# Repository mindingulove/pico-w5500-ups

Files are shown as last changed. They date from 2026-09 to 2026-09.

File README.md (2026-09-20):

# Pico W5500 UPS Battery Monitor

Firmware for a Raspberry Pi Pico UPS controller using W5500 Ethernet and I2C peripherals.

### Assembled DeskPi rack build

<table>
  <tr>
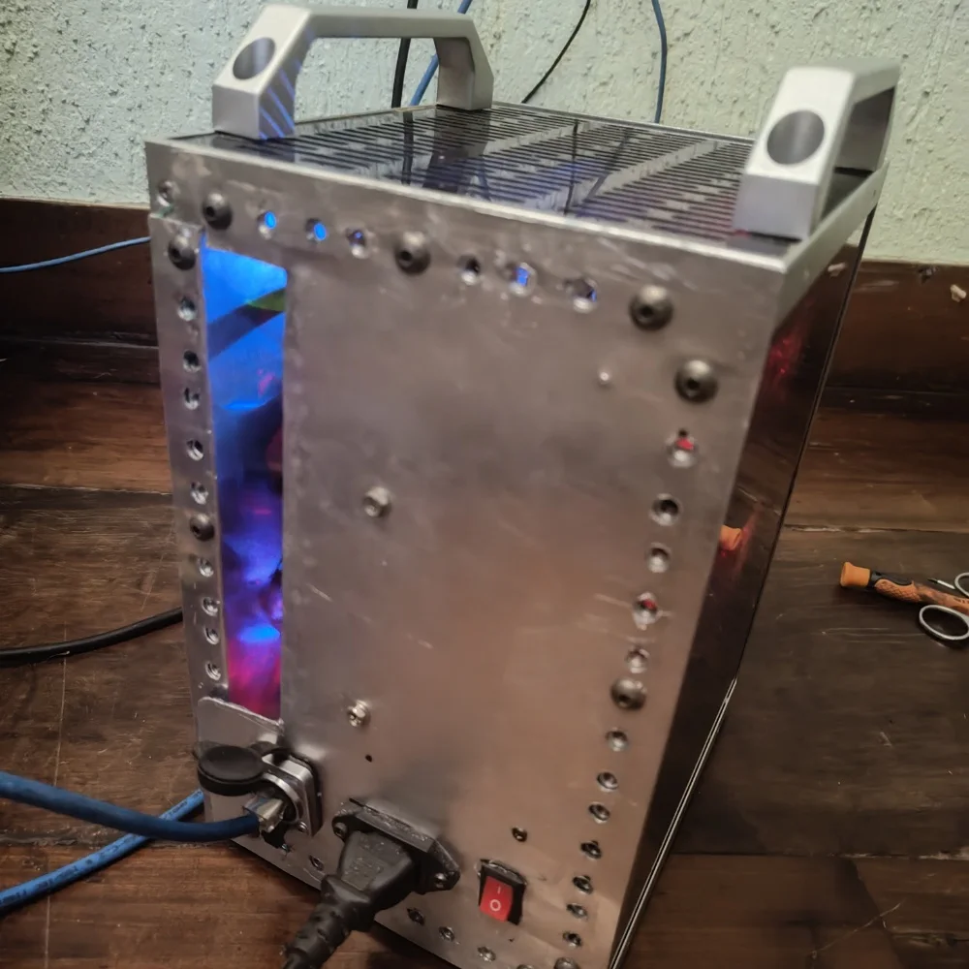
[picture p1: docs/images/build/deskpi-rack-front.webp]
Front of the assembled UPS and DeskPi rack
    <td></td>
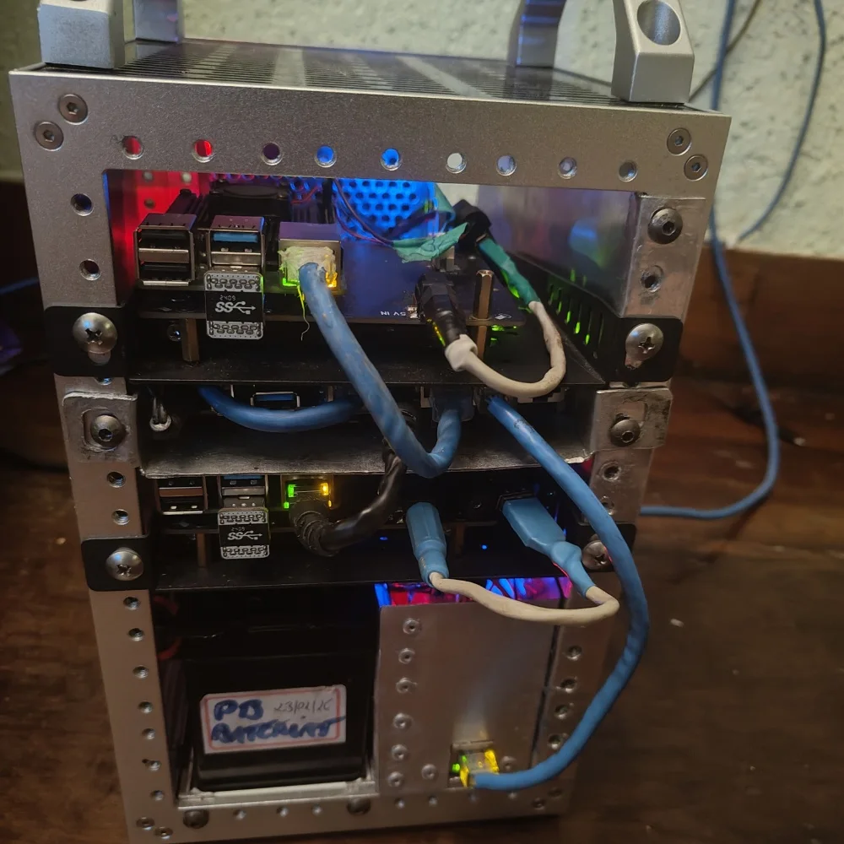
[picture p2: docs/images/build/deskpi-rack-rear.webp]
Rear of the assembled UPS and DeskPi rack
    <td></td>
  </tr>
  <tr>
    <td align="center">Enclosed UPS and rack</td>
    <td align="center">DeskPi rack installation and cabling</td>
  </tr>
</table>

## Hardware

| Device | Interface / address | Purpose |
| --- | --- | --- |
| W5500-EVB-Pico | RP2040 + SPI W5500 Ethernet | Main controller, firmware execution and wired network interface |
| ISO154x | Isolated I2C pass-through | Galvanic isolation between the Pico I2C bus and isolated-side peripherals |
| PC817 two-channel board | Pi GPIO17 to ADS1115 A0/A1 | Isolated host-alive and final-shutdown sensing; both ground-link jumpers must be removed |
| XL9535 | `0x20`-`0x27` | Relay outputs |
| ADS1115 | `0x48`-`0x4B` | Isolated PC817 output sensing; required for outage-time relay cutoff |
| AT24C256 | `0x50`-`0x57` | Persistent battery estimate and configuration |
| LTC2944 | `0x64`-`0x67` | Battery voltage, current and temperature |
| Mini 5 V DC-DC buck | Power | Local regulated 5 V rail |
| Isolated 12 V DC-DC converter | Isolated power | Regulated, galvanically isolated 12 V supply |
| SC-120W-12 UPS/charger | Mains, battery and 12 V output | Main 120 W supply and battery charger |
| Wide-input 5 V USB converter | Power | Regulated 5 V supply for USB-powered loads |

### Bill of materials

AliExpress listings and available variants can change. Match the selected
voltage, current rating, connector pitch and module pinout to the photographed
hardware before ordering or energizing anything.

| Photo | Part and purchase link | Use and required changes |
| --- | --- | --- |
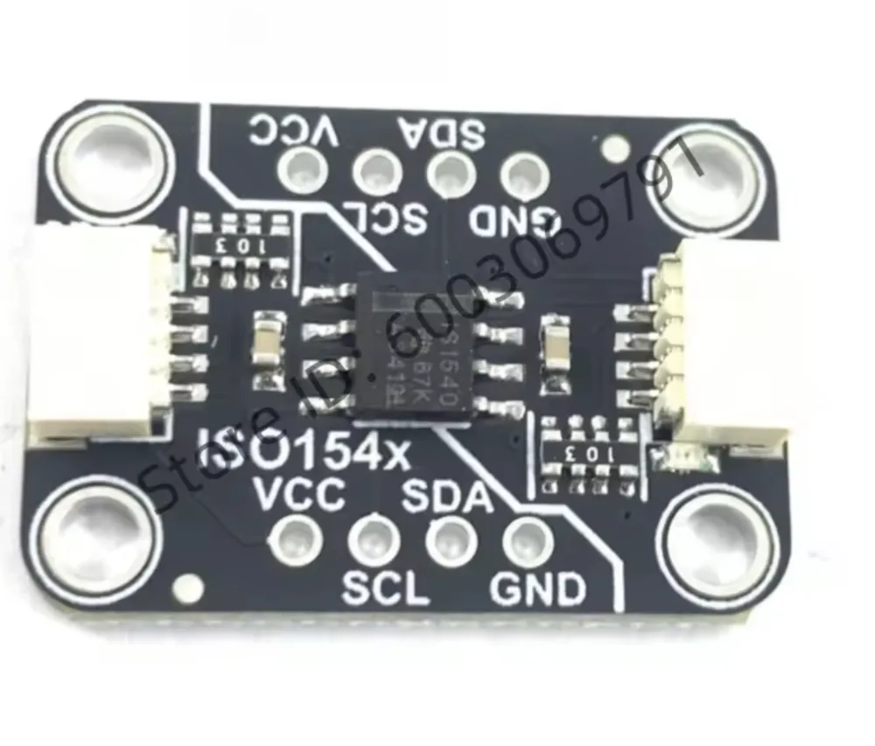
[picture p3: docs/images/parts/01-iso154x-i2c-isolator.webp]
ISO154x I2C isolator module
|  | [ISO154x bidirectional I2C isolator module](https://pt.aliexpress.com/item/1005011832652644.html) | Galvanically isolates the I2C domains. Supply each side from its own domain and do not join grounds across the barrier. |
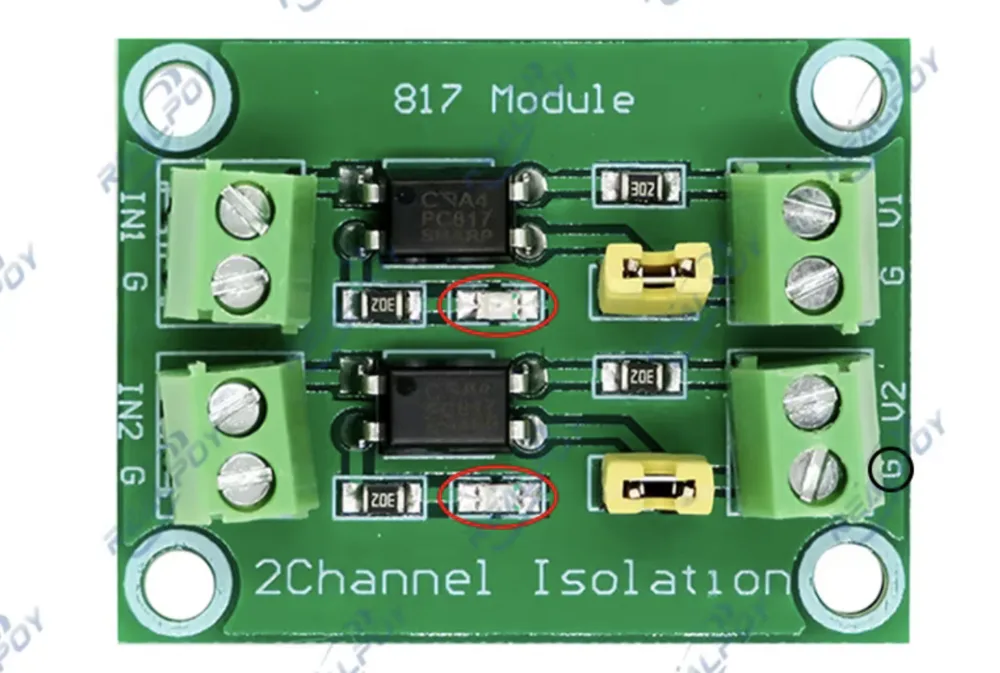
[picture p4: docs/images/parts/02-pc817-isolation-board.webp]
Two-channel PC817 isolation board
|  | [Two-channel PC817 optocoupler isolation board](https://pt.aliexpress.com/item/1005009042140520.html) | Isolates the two Raspberry Pi GPIO17 host-alive signals before ADS1115 measurement. **Remove both yellow jumpers before use**; installed jumpers connect the input and output grounds and defeat galvanic isolation. |
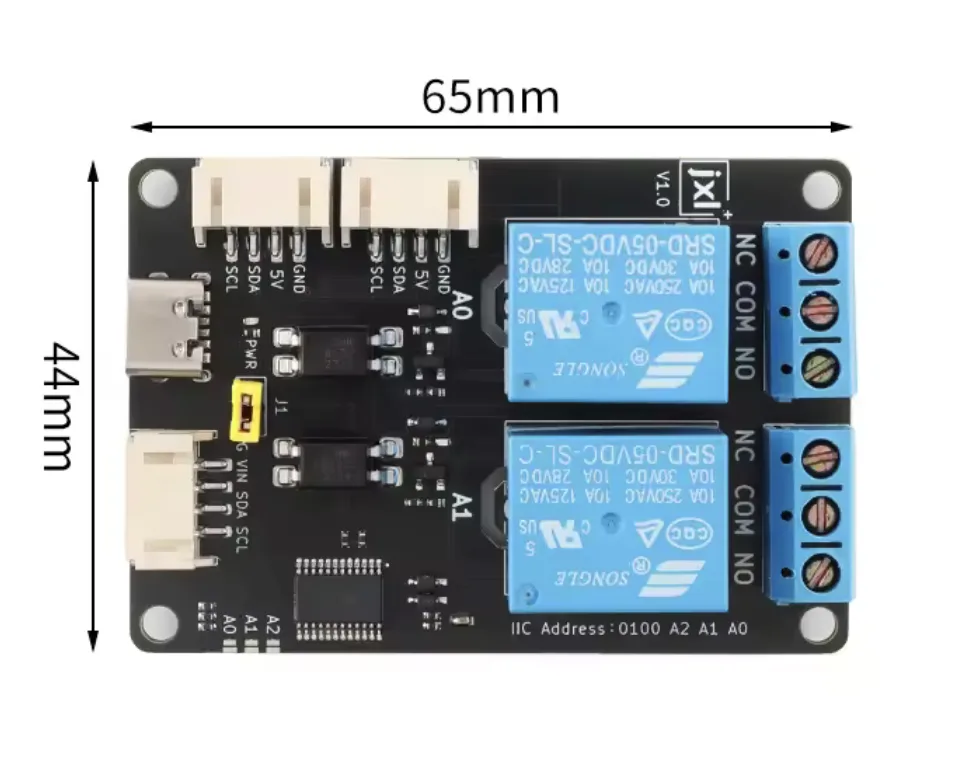
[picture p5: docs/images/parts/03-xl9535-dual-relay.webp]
XL9535 two-channel relay board
|  | [XL9535 I2C relay module](https://pt.aliexpress.com/item/1005005775051224.html) | Two output relays, detected by firmware at address `0x20` by default. This build uses the 5 V relay-board variant. |
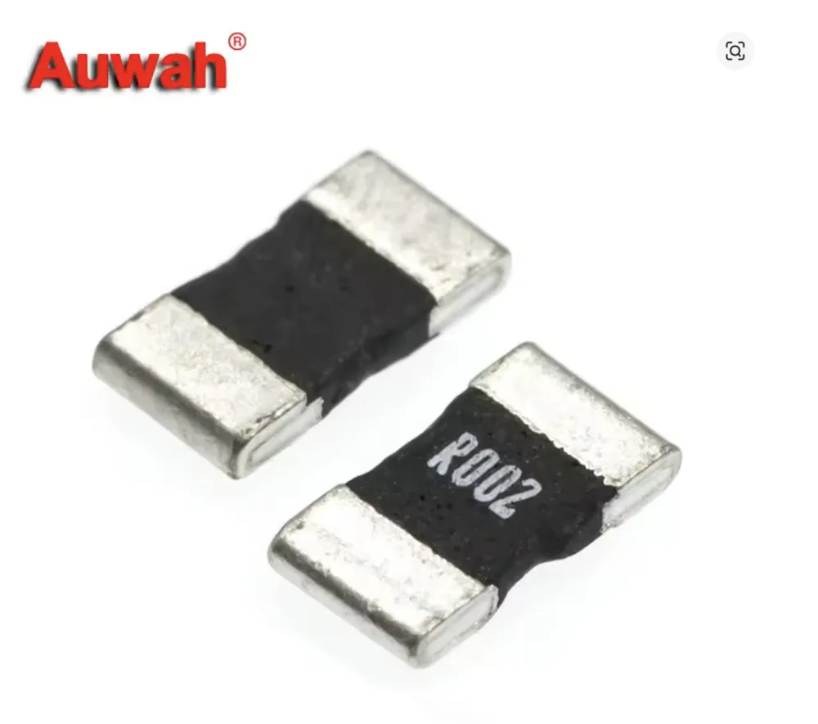
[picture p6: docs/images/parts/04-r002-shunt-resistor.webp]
R002 two milliohm shunt resistor
|  | [R002 shunt resistor](https://pt.aliexpress.com/item/1005003339688820.html) | `0.002 ohm` current shunt used to modify the LTC2944 board below. The firmware constant `LTC_SHUNT_OHMS` is set to `0.002f`. |
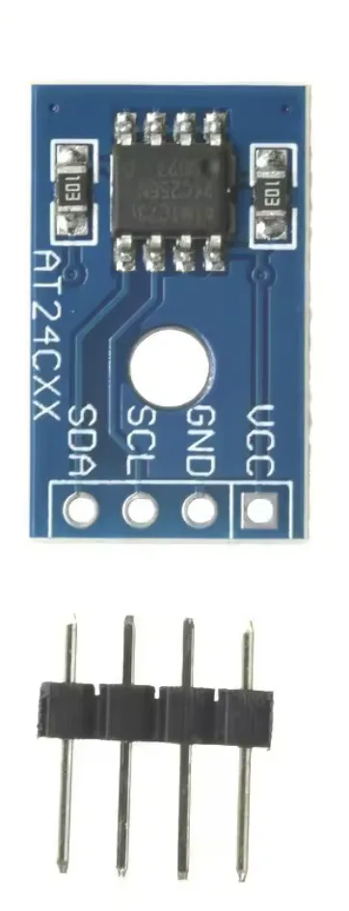
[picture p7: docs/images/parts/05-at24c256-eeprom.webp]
AT24C256 EEPROM module
|  | [AT24C256 I2C EEPROM module](https://pt.aliexpress.com/item/1005007083692220.html) | Stores persistent battery state, configuration and low-battery lockout; address `0x50` by default. |
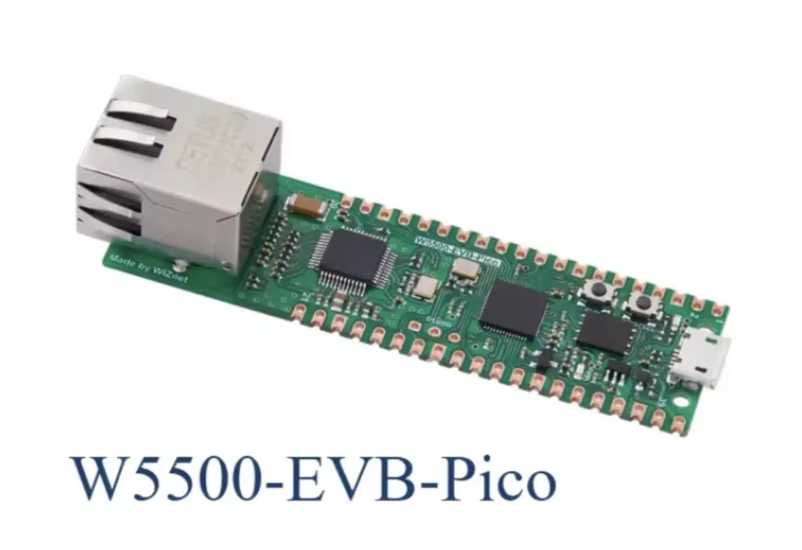
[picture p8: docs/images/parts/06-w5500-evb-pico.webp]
WIZnet W5500-EVB-Pico board
|  | [WIZnet W5500-EVB-Pico](https://pt.aliexpress.com/item/1005008613789535.html) | RP2040 controller with wired W5500 Ethernet. The custom PCB below plugs onto it through female headers. |
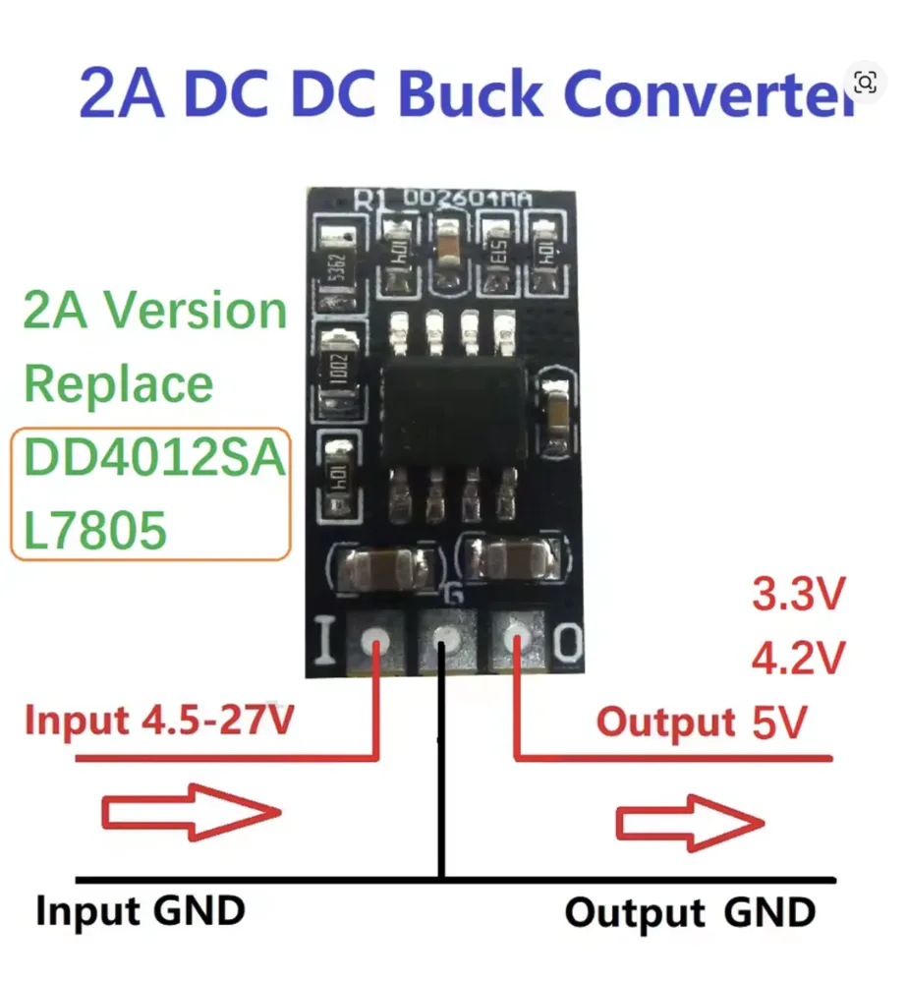
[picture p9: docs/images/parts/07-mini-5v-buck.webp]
Miniature DC-DC buck converter
|  | [Mini DC-DC buck converter](https://pt.aliexpress.com/item/1005004522623517.html) | Use the 5 V output variant shown for the local 5 V rail; verify the output with a meter before connecting electronics. |
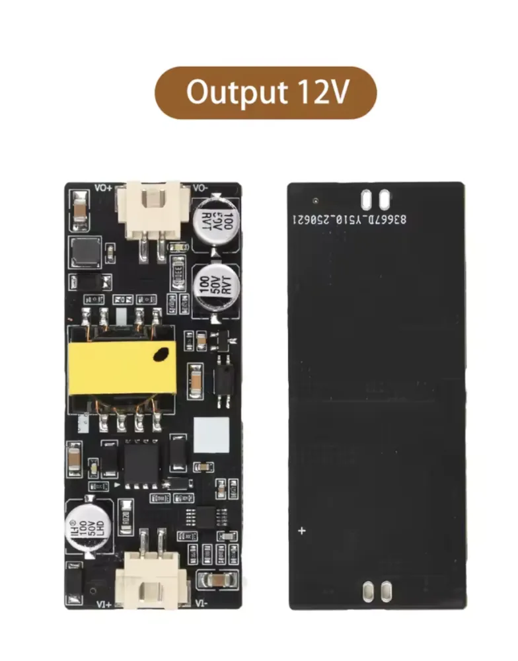
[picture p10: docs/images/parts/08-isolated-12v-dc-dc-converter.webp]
Isolated DC-DC converter with 12 volt output
|  | [Isolated 12 V DC-DC converter module](https://pt.aliexpress.com/item/1005009914339871.html) | Provides a galvanically isolated, regulated 12 V supply. Use the 12 V output variant shown and confirm input range, polarity, isolation and output voltage for the purchased option. |
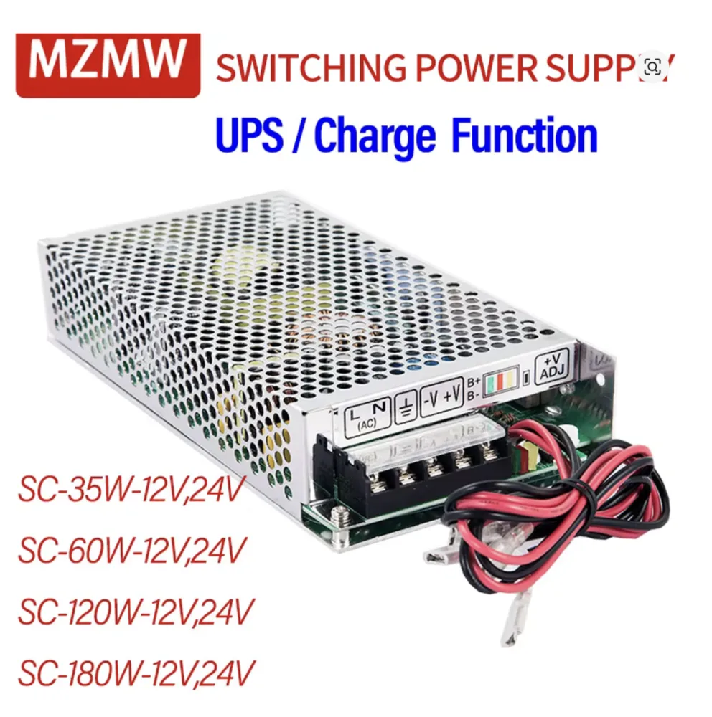
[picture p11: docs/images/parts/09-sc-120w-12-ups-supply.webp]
SC-120W-12 UPS and battery charger power supply
|  | [MZMW SC-series UPS/charger supply](https://pt.aliexpress.com/item/1005005835163230.html) | The pictured build uses the **SC-120W-12 (120 W, 12 V)** option as the mains supply and battery charger. |
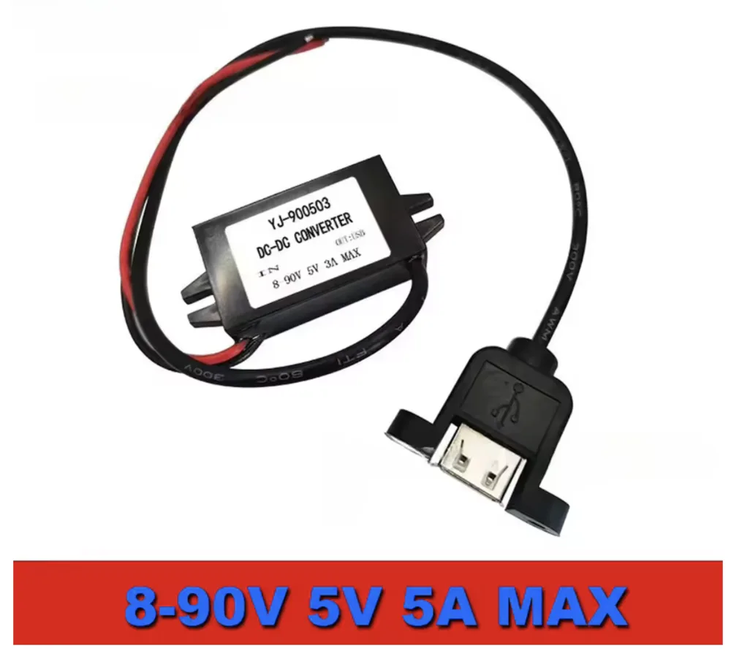
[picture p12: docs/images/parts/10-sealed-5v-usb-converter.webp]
Sealed wide-input 5 volt USB converter
|  | [Wide-input 5 V USB DC-DC converter](https://pt.aliexpress.com/item/1005006466617097.html) | Provides a regulated USB 5 V output. Seller photos show conflicting maximum-current claims, so size and fuse it from the rating printed on the received unit. |
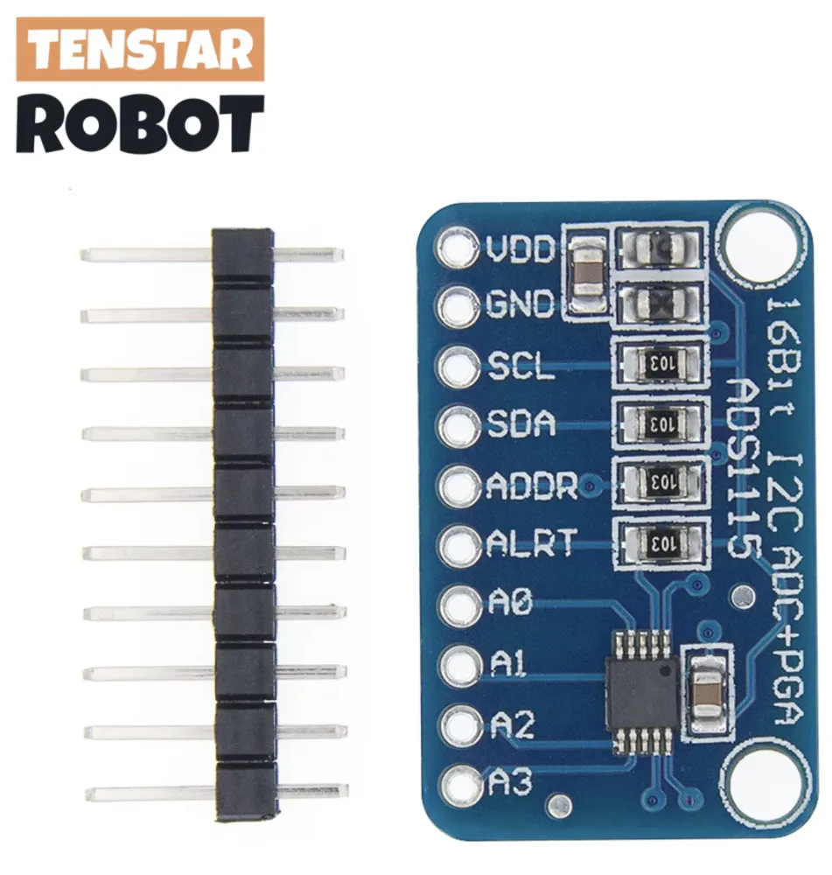
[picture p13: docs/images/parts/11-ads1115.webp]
ADS1115 I2C analog to digital converter
|  | [ADS1115 16-bit I2C ADC module](https://pt.aliexpress.com/item/1005005973975124.html) | Reads the isolated PC817 outputs on A0/Pi1 and A1/Pi2. Tie ADDR to the ADS-side GND for address `0x48`. |
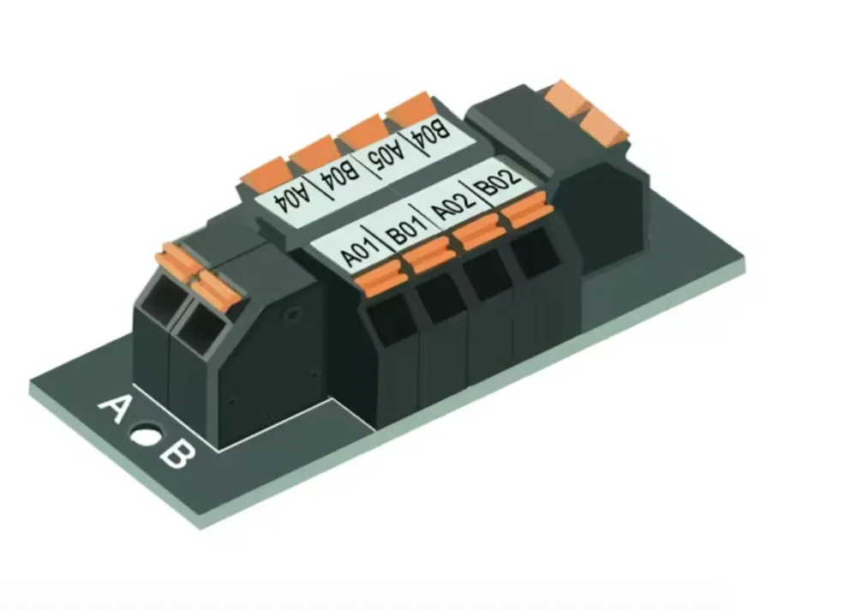
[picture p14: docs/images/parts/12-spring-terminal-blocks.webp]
Spring terminal block connectors
|  | [Spring terminal block connectors](https://pt.aliexpress.com/item/1005010494299157.html) | Board wiring connectors. Select the pitch and pole count that match the PCB footprints and verify orientation before soldering. |
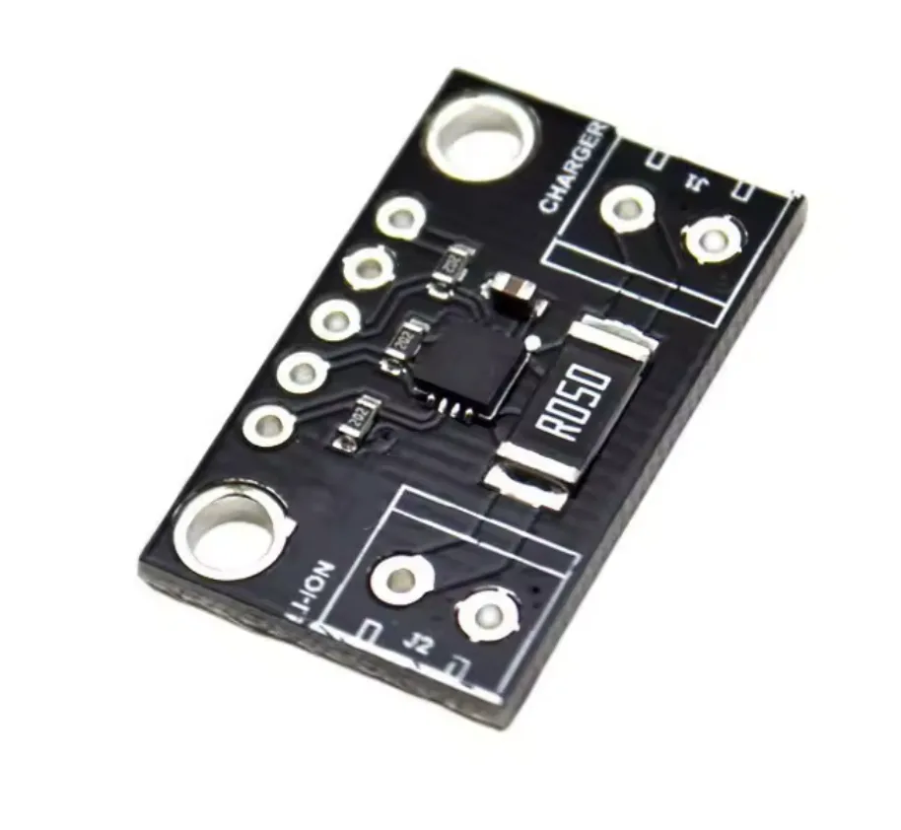
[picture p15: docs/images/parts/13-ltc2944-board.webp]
LTC2944 battery gauge board with original R050 shunt
|  | [LTC2944 battery monitor board](https://pt.aliexpress.com/item/1005006332511347.html) | Measures battery voltage, current and temperature. **Replace the board's original `R050` shunt with the `R002` part listed above** so the hardware matches the firmware's `0.002 ohm` calibration. |
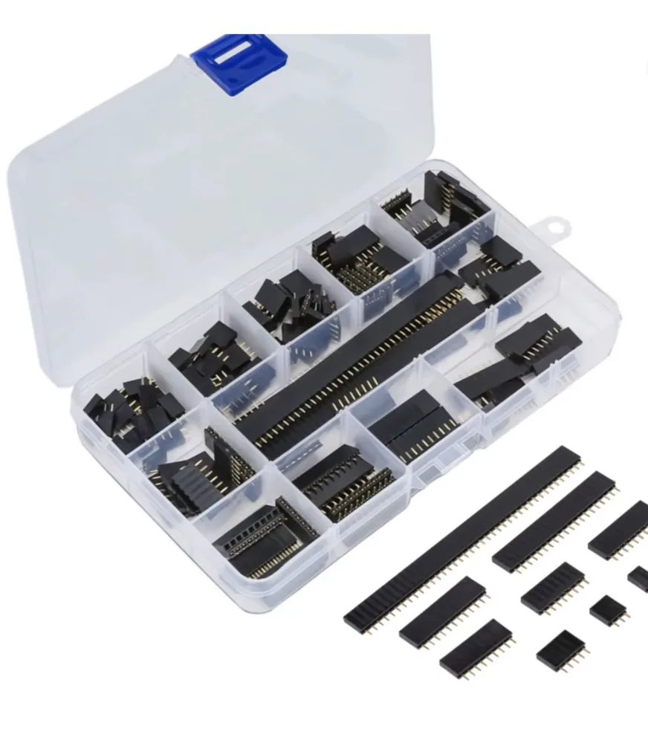
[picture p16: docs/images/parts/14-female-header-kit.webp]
Female PCB header assortment
|  | [Female PCB header assortment](https://pt.aliexpress.com/item/4000523047541.html) | Connects the custom piggyback PCB to the W5500-EVB-Pico. Cut/select the correct lengths and confirm pin alignment before insertion. |

Product photos are identification references supplied by the project owner.
Product names, trademarks and image rights remain with their respective owners.

> [!WARNING]
> The SC-120W supply exposes hazardous mains voltage, and a 12 V battery can
> deliver destructive fault current. Use a grounded enclosure, strain relief,
> insulated covers and correctly rated fuses close to the battery and source.
> Do not work on the assembly while mains or battery power is connected.

### W5500-EVB-Pico piggyback PCB

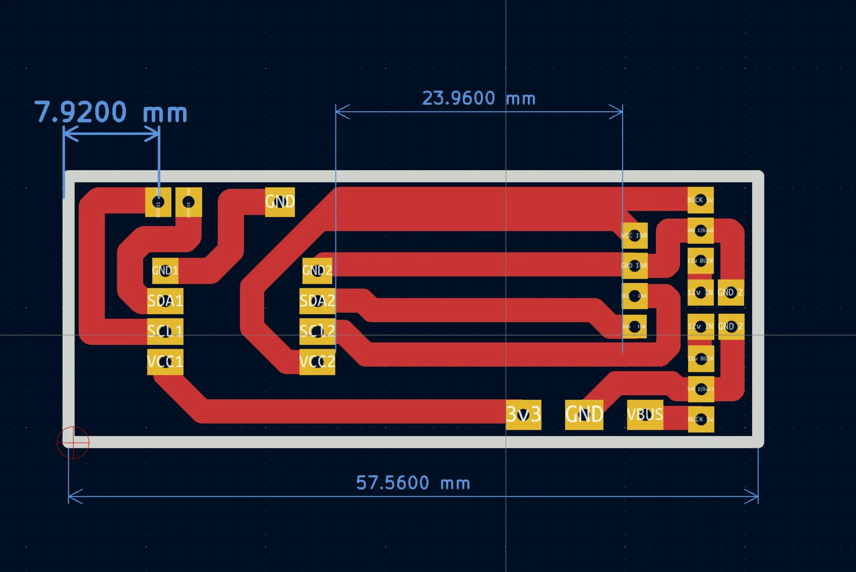
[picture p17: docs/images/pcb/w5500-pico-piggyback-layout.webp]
W5500-EVB-Pico piggyback PCB layout


The custom board is approximately `57.56 mm` long and mounts to the
W5500-EVB-Pico using the [female header
strips](https://pt.aliexpress.com/item/4000523047541.html) listed above. The
editable KiCad board/project and supplied manufacturing outputs are included
under [`hardware/w5500-piggyback`](hardware/w5500-piggyback). The original
folder did not contain a schematic for this board.

- [`source/w5500.kicad_pcb`](hardware/w5500-piggyback/source/w5500.kicad_pcb)
  is the editable board layout.
- [`source/w5500.kicad_pro`](hardware/w5500-piggyback/source/w5500.kicad_pro)
  is the KiCad project configuration.
- [`fabrication/gerber`](hardware/w5500-piggyback/fabrication/gerber) contains
  the supplied Gerber, drill and Gerber-job files.
- [`fabrication/cnc`](hardware/w5500-piggyback/fabrication/cnc) contains the
  supplied isolation-routing, outline and drill CNC files.

The fabrication files are snapshots from the original design folder. Open the
PCB in KiCad, run DRC, verify the board outline, connector orientation and
clearances, and regenerate the manufacturing output before ordering a board or
running a CNC job.

The Pico uses GP12 for SDA and GP13 for SCL. Devices within each ISO1540 power
domain share that domain's ground; do not bridge the isolation barrier. SDA and
SCL must remain at 3.3 V logic levels.

When ADS1115 is missing, firmware uses successful XL9535 relay commands only as an estimated output state. API and MQTT status mark this with `sensed_estimated: true` and `sense_source: "relay_command"`. This is not a physical measurement and never authorizes relay cutoff during an outage.

Power the ADS1115 from its local isolated-side 3.3 V supply. Its GND and ADDR
pins connect to the PC817 output-side GND, selecting I2C address `0x48`. Connect
A0 to the Pi1 PC817 output and A1 to the Pi2 PC817 output; never connect either
Pi power rail or Pi-side ground directly across the isolation barrier.

On the two-channel PC817 board, remove both yellow ground-link jumpers before
connecting it. Leaving either jumper installed bridges that channel's input and
output grounds and defeats the isolation relied upon by this wiring. With the
board fully disconnected and unpowered, verify that input-side GND and
output-side GND are no longer continuous before installing it.

The installed PC817 outputs are active-low and calibrated for the measured
GPIO17 interface levels: approximately `0.017 V` while running and `0.58 V`
after the shutdown signal is released. Firmware must first observe an ADS
channel at or below `0.10 V` for 10 seconds while the Pi is running. After the
shutdown request, it must observe the channel at or above `0.45 V` for 30
seconds before permitting that Pi's relay to turn off. Readings between the two
thresholds are indeterminate and fail closed. A channel that starts in the OFF
range cannot authorize cutoff because the preceding running state was not seen.
The API/MQTT `ads_v` field displays the inverted logical Pi voltage
(`3.30 V - PC817 output`); `ads_raw_v` retains the actual ADC measurement used
by the safety interlock.

For GPIO-based host-alive sensing, install `ups_gpio_alive.service` so GPIO17
(physical pin 11) is driven HIGH after boot. Install the executable
`ups_gpio_shutdown_final` as
`/usr/lib/systemd/system-shutdown/ups_gpio_shutdown_final`; it drives GPIO17
LOW only for the final `poweroff` or `halt` phase, after normal services have
stopped. The hook runs `sync` and fails closed unless every persistent
filesystem visible in `/proc/mounts` is unmounted or read-only. Do not use an
ordinary service `ExecStop` for the LOW transition because that runs too early
to prove shutdown is complete.

## Network

- Static IP: `192.168.6.122`
- HTTP status: `http://192.168.6.122/api/status`
- NUT server: `192.168.6.122:3493`, UPS name `pico-ups`
- MQTT broker: `192.168.6.245:1883`
- MQTT base topic: `ups/battery/main`

MQTT connection requires a working Ethernet link. `rc=-2` means the TCP connection to the broker failed.

## PVE-UPS / NUT

The Pico exposes a read-only NUT protocol endpoint for PVE-UPS on TCP port
`3493`. Configure the PVE-UPS source as:

- Type: `NUT server`
- Host: `192.168.6.122`
- Port: `3493`
- UPS name: `pico-ups`
- Username/password: leave blank

The endpoint implements the anonymous `LIST VAR` operation used by PVE-UPS and
also supports `LIST UPS`, `VER`, `PROTVER`, and `LOGOUT`. It does not accept NUT
write or instant commands. Keep TCP port 3493 restricted to the trusted
management LAN because the NUT protocol is unencrypted.

`ups.status` changes to `OB` only after battery discharge is confirmed for five
seconds. Once on battery, it remains latched until voltage is at least `13.60 V`
with non-discharging current for 30 seconds. This prevents falling server load
during shutdown from being misreported as restored utility power. Sensor loss
is reported as `NOCOMM`, never as `OL`.

With PVE-UPS configured to shut PBS down first and the Proxmox host last at
`10%` charge, the Pico arms a RAM-only external-shutdown handoff when its NUT
state is `OB` and SOC reaches `10%`. Arming never authorizes relay cutoff by
itself. The Pico waits at least 60 seconds and requires every still-powered
host's ADS/PC817 channel to complete the normal running-to-final-OFF proof.
Only then does it persist the low-battery lockout and remove relay power.

If utility returns while PVE-UPS is completing shutdown, the handoff remains
armed for five minutes. A completed final-OFF proof during that window causes
the safe relay cutoff, followed by the normal confirmed automatic restoration,
so halted hosts receive an OFF-to-ON start. If no complete proof arrives, the
RAM latch expires without changing a relay. If PVE-UPS fails, the existing 5%
local shutdown agents remain the fallback. If both methods fail, GPIO stays in
the running state and relay cutoff remains blocked, including at `10.8 V`.
The status API exposes `pve_ups_handoff_armed`,
`pve_ups_handoff_cutoff_ready`, and
`pve_ups_handoff_recovery_remaining_sec` for diagnosis.

The Pico publishes `battery.runtime` only while it has a meaningful live
discharge estimate. PVE-UPS can always use its on-battery and charge triggers;
the runtime trigger becomes available during a measurable discharge. Output
load percentage is deliberately omitted because the measured signed battery
power is not the same as UPS output load relative to a rated capacity.

## Home Assistant: MQTT And HTTP Sensors

Both telemetry paths are intentionally available at the same time:

- MQTT discovery creates source-specific entities such as
  `sensor.ups_battery_main_mqtt_soc`,
  `sensor.ups_battery_main_mqtt_power`, and
  `sensor.ups_battery_main_mqtt_runtime`. These entities are attached to the
  `Server UPS` MQTT device. Their concise entity names (`SOC`, `Voltage`,
  `Current`, `Power`, `Temperature`, `Energy`, and `Runtime`) keep dashboard
  headings and graph legends readable without changing their entity IDs.
- The Home Assistant package polls `GET /api/status` every 15 seconds through
  `sensor.ups_pico_raw_status` and keeps the existing HTTP-derived entities,
  including `sensor.ups_battery_main_soc`,
  `sensor.ups_battery_main_power`, and
  `sensor.ups_battery_main_runtime`. Their display names include `HTTP` so the
  two sources are unambiguous while existing dashboard entity IDs continue to
  work.

MQTT and HTTP values should normally match, allowing either path to be graphed
or used in automations. The MQTT runtime text reports `Charging`, `Idle`, or a
remaining-time value instead of exposing the firmware's internal `-1` sentinel.
The numeric MQTT runtime-minutes entity has no numeric state while charging or
idle. The Pico subscribes to Home Assistant's `homeassistant/status` birth
topic and republishes discovery when Home Assistant reconnects.

`power_w` is signed battery power flow, not a direct measurement of total server
load. Positive values indicate charging and negative values indicate discharge.
`sensor.ups_battery_main_estimated_load_w` remains a Home Assistant-configured
outage-load estimate used when a live discharge runtime cannot be calculated.

## Local Configuration

Create the private firmware configuration before building:

```sh
cp ups_secrets.example.h ups_secrets.h
```

Set `UPS_OTA_TOKEN` and `UPS_CALIBRATION_TOKEN` to different long random
values. Set `UPS_MQTT_USER` and `UPS_MQTT_PASSWORD` when the broker requires
authentication; leave both empty for anonymous MQTT. Keep the matching
calibration token in the Home Assistant `rest_command` URLs. For the included
Home Assistant package, copy `homeassistant_ups_package.example.yaml` to
`homeassistant_ups_package.yaml` and replace
`replace_with_calibration_token` locally. The real `ups_secrets.h`, Home
Assistant package, `.env`, generated firmware, and private `plans/` tree are
excluded from Git.

## Build

Use the provided script so every firmware has the required OTA flash layout:

```sh
./build_ota.sh
```

The layout is `2 MB flash: 1 MB sketch + 1 MB LittleFS`. Output files are:

```text
build/ota/ups_battery_monitor.ino.bin
build/ota/ups_battery_monitor.ino.uf2
```

Do not build OTA releases with `2 MB (no FS)`. OTA staging and rollback will not work without the 1 MB LittleFS partition.

## First Installation

The OTA-capable firmware must be installed once over USB:

1. Hold BOOTSEL while connecting the Pico.
2. Copy `build/ota/ups_battery_monitor.ino.uf2` to the `RPI-RP2` volume.
3. Confirm the serial log or `/api/status` reports `Firmware: pve-ups-handoff-2026-09-20`.
4. Confirm Ethernet link and `192.168.6.122` are reachable.

Future updates can use Ethernet.

### Upgrading From A No-LittleFS Build

Check the `hardware.littlefs` field returned by `/api/status`. If it is `false`, the installed firmware uses the old `2 MB (no FS)` layout and cannot stage or roll back an Ethernet update. An attempted upload will be rejected without changing the running firmware:

```text
HTTP 507
{"ok":false,"error":"backup_failed"}
```

Install the UF2 once through BOOTSEL as described above. After `/api/status` reports `littlefs:true`, subsequent releases can use `./pico_admin.sh upload`.

## Ethernet Firmware Update

Build and upload:

```sh
./build_ota.sh
./pico_admin.sh upload
```

To upload a specific binary:

```sh
./pico_admin.sh upload /path/to/firmware.bin
```

The HTTP updater accepts the Arduino `.bin` file. Never upload a `.uf2` file to the HTTP endpoint.

The update token is stored in the untracked `ups_secrets.h`. Keep it private
and use a unique random value. The update API uses plain HTTP and is intended
for a trusted LAN.

Direct API request:

```text
POST /api/firmware?token=<UPS_OTA_TOKEN>
Content-Type: application/octet-stream
Content-Length: <firmware size>
X-Firmware-CRC32: <8 hexadecimal digits>

<raw Arduino .bin data>
```

`pico_admin.sh` first performs the RP2040 image checks locally, then calculates
and sends the CRC32 automatically. This also prevents an accidental `.uf2`
upload when the board is still running an older, permissive updater. Direct API
clients must provide the header; it detects corruption or a truncated/mixed
upload but is not a cryptographic signature. Authentication still depends on
the update token and the trusted LAN.

## Update Safety And Rollback

Firmware updates use the Arduino-Pico OTA bootloader:

1. The running image is copied to LittleFS as `/previous.bin`.
2. The previous rollback image remains recoverable while its replacement is committed.
3. The HTTP body is first written to `/firmware.tmp`, so an interrupted upload
   cannot become an installable candidate.
4. The candidate length, full-file CRC32, RP2040 boot2 CRC, initial stack
   pointer, and reset vector are validated. This rejects `.uf2`, random data,
   corruption, and incomplete `.bin` uploads.
5. Only a valid image is atomically renamed to `/firmware.bin`.
6. The boot-attempt marker must be written successfully before the PicoOTA
   bootloader command is committed.
7. The candidate is staged in LittleFS, then the Pico restarts.
8. The bootloader installs the candidate. Interrupted staging or installation is retried after power returns.
9. The candidate must run the main loop for 60 seconds with Ethernet link up.
10. An 8-second watchdog resets a candidate that hangs after startup.
11. After three failed candidate boots, `/previous.bin` is automatically restored.

This keeps the useful design from `JAndrassy/ArduinoOTA`—receive into a storage
object, close it, then apply it—while retaining this firmware's HTTP endpoint,
LittleFS rollback image, boot-attempt marker, watchdog, and automatic rollback.
The generic library's blocking receive loop was not copied; this implementation
retains a 10-second no-data timeout and verifies every filesystem write.

The health marker is only forgotten after `/ota.pending` is actually removed. A transient filesystem deletion failure is retried and cannot silently turn a healthy candidate into a later false rollback.

Useful OTA failure responses:

| HTTP | Error | Meaning |
| --- | --- | --- |
| `403` | `bad_token` | Authentication token did not match |
| `411` | `invalid_content_length` | Missing, too small, or oversized firmware body |
| `400` | `missing_firmware_crc32` | Client omitted the required `X-Firmware-CRC32` header |
| `409` | `candidate_not_healthy` | Current candidate is still inside its 60-second health window |
| `507` | `littlefs_unavailable` | Required OTA filesystem is not mounted |
| `507` | `backup_failed` | Running firmware could not be retained in LittleFS |
| `507` | `candidate_no_space` | LittleFS cannot retain both rollback and candidate images |
| `507` | `candidate_open_failed` | Candidate temporary file could not be created |
| `507` | `candidate_commit_failed` | Validated temporary file could not be atomically renamed |
| `507` | `pending_marker_failed` | Rollback boot marker could not be persisted |
| `507` | `staging_failed` | PicoOTA bootloader command could not be committed |
| `400` | `invalid_or_incomplete_firmware` | Transfer, CRC32, or RP2040 image validation failed |

Manual rollback:

```sh
./pico_admin.sh rollback
```

Application-managed rollback cannot recover code that fails before the OTA boot guard itself can execute. The RP2040 ROM BOOTSEL loader remains the final recovery method: hold BOOTSEL and install the last known-good UF2 over USB.

## Pico Soft Restart

A soft restart reboots only the Pico firmware; it is not an eight-second relay power cycle. During normal operation startup commands both configured UPS output relays on. After a low-battery cutoff, however, a persistent EEPROM lockout overrides that policy and keeps both outputs off across Pico resets and complete battery loss.

HTTP:

```sh
./pico_admin.sh restart
```

Direct endpoint:

```text
POST /api/system/restart?token=<UPS_OTA_TOKEN>
```

MQTT:

```text
Topic:   ups/system/restart/set
Payload: restart
```

Home Assistant MQTT discovery creates an `UPS Pico Restart` button automatically.

## Graceful Load Shutdown

At low battery, firmware does not immediately cut relay power:

1. Critical SOC, discharge current and non-charging voltage must persist for 30 seconds.
2. The configured shutdown HTTP endpoint must return an HTTP `2xx` response.
3. Failed shutdown requests are retried every 15 seconds.
4. After an accepted request, firmware waits at least 60 seconds. This is only
   a minimum delay: relay cutoff remains blocked for as long as the host-alive
   GPIO stays HIGH or its OFF state has not been stable for 30 seconds.
5. With ADS1115 present, each Pi relay can be removed only after its active-low PC817 output was first confirmed low while running and is then confirmed high for 30 seconds after shutdown.
6. The `10.8 V` emergency condition does not bypass this ADS host-off interlock.

The PVE-UPS 10% handoff uses the same ADS interlock. It does not replace or
weaken the independent 5% shutdown-request fallback described above.

The shutdown remains armed when host load falls during operating-system shutdown. Reduced discharge current alone is not interpreted as utility recovery. Cancellation requires at least `13.60 V` and non-discharging current continuously for 30 seconds.

Immediately before an ADS-authorized relay cutoff, the firmware stores a low-battery lockout flag in the AT24C256. On any subsequent Pico boot, the XL9535 output latch is prepared with both relay outputs off before those pins become outputs, avoiding an on/off boot pulse. The lockout is exposed by `/api/status` as `low_battery_lockout`.

Default shutdown endpoints are configured in `loadDefaultConfig()` and must correspond to real services that perform an orderly host shutdown.

For the Pi 3.3 V rail to fall after a clean halt, Raspberry Pi 4 bootloader
configuration must use `POWER_OFF_ON_HALT=1` and `WAKE_ON_GPIO=0`. Change these
only after the ADS wiring and live high reading have been verified. Otherwise a
halted Pi may not restart as expected.

### Operation Without ADS1115

Without ADS1115, firmware never turns a relay off during the outage, including
at `10.8 V`. If SOC reaches `3%` or less while utility voltage is absent, firmware records a
RAM-only assumption that the shutdown agents have already halted the Pis. When
utility recovery (`>=13.60 V`, current `>=-0.05 A`, SOC `>=7%`) then remains
valid for two minutes, each enabled relay that is still on is cycled off for
eight seconds and restored once, allowing the halted Pis to boot.

The latch is intentionally not stored in EEPROM. If the battery becomes fully
flat, the Pico and relay board lose power and the relays physically drop out.
When power returns, normal boot policy commands both relays on, which already
provides the required off-to-on restart; losing the RAM latch prevents an
unnecessary second cycle. A pre-existing persistent low-battery lockout still
uses the normal confirmed-utility restoration path.

### Automatic Power Restoration

Automatic restoration starts only after the low-battery sequence has completed and the relays were cut. The firmware does not treat a single voltage rise as proof that utility power is stable. All of the following evidence must remain true continuously:

| Condition | Required value |
| --- | --- |
| Battery voltage | At least `13.60 V` |
| Battery current | At least `-0.05 A` (not materially discharging) |
| Battery SOC | At least `7%` |
| Confirmation time | Two minutes |

If any condition fails during confirmation, the timer resets. After successful confirmation, both relays are enabled, the EEPROM lockout is cleared, and the hosts boot again. If only one relay write succeeds, that safely restored output remains on while firmware restarts confirmation and retries the missing output; it is never cut again merely to make the retry symmetrical. An explicit manual power-on command also clears the persistent lockout after the requested relay write succeeds.

Expected serial sequence:

```text
[LOW_BATTERY] Stage -> done.
[RELAY] Boot lockout active; outputs remain off pending confirmed utility recovery.
[AUTO_RESTORE] Utility recovery detected; confirming for 120s (...)
[AUTO_RESTORE] Utility recovery confirmed; enabling output relays.
[RELAY] Pi1 -> on ... (ok)
[RELAY] Pi2 -> on ... (ok)
[AUTO_RESTORE] Output relays restored; low-battery stage -> idle.
```

The automatic restoration path applies only to a low-battery cutoff. A manual graceful shutdown intentionally remains off until a manual power-on command or Pico restart. The Pico retries a manual host shutdown request until it receives HTTP `2xx`, waits the same 60-second minimum grace period, and only then disables that output relay if ADS confirms the Pi is already off. Direct `/power/off` requests are also subject to the ADS interlock and are intentionally not exposed as Home Assistant buttons.

## Main HTTP Endpoints

| Method | Path | Purpose |
| --- | --- | --- |
| GET | `/status` | Legacy battery status |
| GET | `/api/status` | Full battery, relay and hardware status |
| GET | `/api/battery/status` | Battery capacity status |
| GET | `/api/log` | Recent firmware/serial log from a bounded RAM buffer |
| POST | `/api/pi/1/power/on` | Enable Pi1 output |
| POST | `/api/pi/1/power/off` | Disable Pi1 output only when ADS host-off proof permits it |
| POST | `/api/pi/1/shutdown` | Gracefully shut down Pi1, then disable its relay |
| POST | `/api/pi/2/shutdown` | Gracefully shut down Pi2, then disable its relay |
| POST | `/api/pi/all/shutdown` | Gracefully shut down both hosts, then disable both relays |
| POST | `/api/pi/1/power-cycle` | Cycle Pi1 only when ADS host-off proof permits relay-off |
| POST | `/api/pi/2/power-cycle` | Cycle Pi2 only when ADS host-off proof permits relay-off |
| POST | `/api/pi/all/power-cycle` | Cycle both only when each ADS host-off proof permits relay-off |
| POST | `/api/firmware` | Stage a `.bin` firmware update; token required |
| POST | `/api/firmware/rollback` | Restore retained firmware; token required |
| POST | `/api/system/restart` | Soft-restart the Pico; token required |

The same recent diagnostic output shown over USB serial can be retrieved over
Ethernet without writing logs to flash:

```bash
curl http://192.168.6.122/api/log
./pico_admin.sh log
```

The endpoint returns the most recent 8 KiB as `text/plain`. Older lines are
discarded automatically when the RAM ring buffer fills.

## Diagnostics

A healthy I2C bus is idle high:

```text
[I2C] Idle levels before scan: SDA=1 SCL=1
```

The complete expected scan is normally:

```text
0x20
0x48
0x50
0x64
```

ADS1115 is optional for telemetry and no-ADS recovery mode, but required for
any relay cutoff while the UPS remains on battery. XL9535, AT24C256 and LTC2944
should remain detectable.

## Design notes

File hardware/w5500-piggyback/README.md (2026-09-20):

# W5500-EVB-Pico Piggyback PCB

This directory contains the current top-level piggyback board imported from the
original `pico w5500s` KiCad design folder.

W5500-EVB-Pico piggyback PCB layout

## Contents

- `source/w5500.kicad_pcb`: editable PCB layout
- `source/w5500.kicad_pro`: KiCad project configuration
- `fabrication/gerber/`: supplied front-copper, edge, drill and job files
- `fabrication/cnc/`: supplied isolation-routing, edge-cut and drill CNC files

No matching schematic file was present for this board. Older version folders,
automatic backups, FlatCAM project state, KiCad local preferences, caches and
macOS metadata were intentionally not imported.

The supplied fabrication files were generated separately from the editable
source and may not represent its newest saved state. Before fabrication, open
the PCB in KiCad, run DRC, verify the approximately `57.56 mm` board length,
connector pitch/orientation and all clearances, then regenerate the required
Gerber/drill or CNC files.

The board attaches to the W5500-EVB-Pico with female header strips. Confirm the
header alignment and orientation before applying power.

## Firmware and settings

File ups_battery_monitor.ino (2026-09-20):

#include <SPI.h>
#include <Ethernet.h>
#include <EthernetUdp.h>
#include <PubSubClient.h>
#include <Wire.h>
#include <LittleFS.h>
#include <PicoOTA.h>
#include "ups_secrets.h"
#define MDNS_USING_ETHERNET true
#include <MDNS_Generic.h>

#include <math.h>
#include <string.h>
#include <strings.h>

// Mirror every firmware log line to USB serial and to a bounded RAM ring buffer.
// The HTTP log endpoint reads this buffer; no diagnostic output is written to
// LittleFS or EEPROM, avoiding flash wear during long-running operation.
class BufferedSerialLog : public Print {
 public:
  static const size_t CAPACITY = 8192;

  void begin(unsigned long baud) {
    ::Serial.begin(baud);
  }

  operator bool() const {
    return (bool)::Serial;
  }

  size_t write(uint8_t value) override {
    ::Serial.write(value);
    buffer_[head_] = (char)value;
    head_ = (head_ + 1U) % CAPACITY;
    if (size_ < CAPACITY) size_++;
    return 1;
  }

  using Print::write;

  size_t size() const {
    return size_;
  }

  char at(size_t index) const {
    if (index >= size_) return '\0';
    size_t oldest = (head_ + CAPACITY - size_) % CAPACITY;
    return buffer_[(oldest + index) % CAPACITY];
  }

 private:
  char buffer_[CAPACITY] = {0};
  size_t head_ = 0;
  size_t size_ = 0;
};

BufferedSerialLog bufferedSerialLog;
#define Serial bufferedSerialLog

const char* FIRMWARE_VERSION = "pve-ups-handoff-2026-09-20";

// ============================================================================
// Pico + W5500 wiring
// ============================================================================
#define I2C_SDA          12
#define I2C_SCL          13

#define W5500_CS         17
#define W5500_SCK        18
#define W5500_MOSI       19
#define W5500_MISO       16
#define W5500_RST        20

IPAddress FALLBACK_IP (192, 168, 6, 122);
IPAddress FALLBACK_DNS(192, 168, 6, 1);
IPAddress FALLBACK_GW (192, 168, 6, 1);
IPAddress FALLBACK_SN (255, 255, 255, 0);

byte mac[] = { 0xDE, 0xAD, 0xBE, 0xEF, 0xFE, 0x05 };

const char*     HOSTNAME  = "pico-ups";
const uint16_t  HTTP_PORT = 80;
const uint16_t  NUT_PORT = 3493;
const char*     NUT_UPS_NAME = "pico-ups";
const char*     NUT_UPS_DESCRIPTION = "Pico W5500 UPS";

IPAddress MQTT_BROKER_IP(192, 168, 6, 245);
const uint16_t MQTT_PORT = 1883;
const char* MQTT_USER = UPS_MQTT_USER;
const char* MQTT_PASSWORD = UPS_MQTT_PASSWORD;
const char* MQTT_CLIENT_ID = "pico-ups";
const char* MQTT_BASE_TOPIC = "ups/battery/main";
const char* MQTT_STATE_TOPIC = "ups/battery/main/state";
const char* MQTT_AVAILABILITY_TOPIC = "ups/battery/main/availability";
const char* MQTT_CALIBRATE_SET_TOPIC = "ups/battery/main/calibrate/set";
const char* MQTT_CALIBRATE_STATUS_TOPIC = "ups/battery/main/calibrate/status";
const char* MQTT_PI1_POWER_SET_TOPIC = "ups/pi/1/power/set";
const char* MQTT_PI2_POWER_SET_TOPIC = "ups/pi/2/power/set";
const char* MQTT_ALL_POWER_SET_TOPIC = "ups/pi/all/power/set";
const char* MQTT_POWER_STATUS_TOPIC = "ups/pi/power/status";
const char* MQTT_SYSTEM_RESTART_TOPIC = "ups/system/restart/set";
const char* MQTT_HOME_ASSISTANT_STATUS_TOPIC = "homeassistant/status";
const uint32_t MQTT_RECONNECT_INTERVAL_MS = 10000UL;

const char* OTA_PREVIOUS_FILE = "/previous.bin";
const char* OTA_PREVIOUS_TEMP_FILE = "/previous.tmp";
const char* OTA_PREVIOUS_OLD_FILE = "/previous.old";
const char* OTA_CANDIDATE_FILE = "/firmware.bin";
const char* OTA_CANDIDATE_TEMP_FILE = "/firmware.tmp";
const char* OTA_PENDING_FILE = "/ota.pending";
const uint8_t OTA_MAX_BOOT_ATTEMPTS = 3;
const uint32_t OTA_HEALTH_CONFIRM_MS = 60000UL;
const uint32_t OTA_WATCHDOG_MS = 8000UL;
const uint32_t OTA_UPLOAD_IDLE_TIMEOUT_MS = 10000UL;
const size_t OTA_MIN_IMAGE_SIZE = 4096UL;
const size_t OTA_MAX_IMAGE_SIZE = 900UL * 1024UL;
const size_t OTA_FS_RESERVE_BYTES = 8192UL;
const size_t OTA_RP2040_HEADER_SIZE = 264UL;

extern uint8_t __flash_binary_end;

// ============================================================================
// I2C peripherals
// ============================================================================
uint8_t LTC2944_ADDR = 0x64;
uint8_t ADS1115_ADDR = 0x48;
uint8_t XL9535_ADDR  = 0x20;
uint8_t AT24C256_ADDR = 0x50;

const uint8_t XL9535_RELAY_PIN_PI1 = 0;
const uint8_t XL9535_RELAY_PIN_PI2 = 1;
const bool RELAY_ACTIVE_HIGH = true;

const float LTC_SHUNT_OHMS       = 0.002f;
const float BATTERY_CAPACITY_AH  = 7.0f;
const float BATTERY_NOMINAL_V    = 12.0f;
const float USABLE_CAPACITY_PCT  = 0.75f;
const float CHARGE_EFFICIENCY    = 0.85f;
const float MIN_RUNTIME_LOAD_W   = 0.5f;
const float CURRENT_DEADBAND_A   = 0.05f;
const float FULL_FLOAT_VOLTAGE   = 13.40f;
const float FULL_CURRENT_A       = 0.25f;
const float CRITICAL_VOLTAGE     = 10.80f;
const uint32_t FULL_CONFIRM_MS   = 20UL * 60UL * 1000UL;

const uint32_t SAVE_INTERVAL_MS      = 10UL * 60UL * 1000UL;
const uint32_t MIN_SAVE_INTERVAL_MS  = 60UL * 1000UL;
const float    SAVE_DELTA_WH         = 0.5f;
const float    SAVE_DELTA_PERCENT    = 1.0f;
const uint32_t TELEMETRY_INTERVAL_MS = 5000UL;
const uint32_t POWER_CYCLE_OFF_MS    = 8000UL;
const uint32_t POWER_CYCLE_FAILSAFE_MS = 30000UL;
const uint32_t LOW_BATTERY_CONFIRM_MS = 30000UL;
const uint32_t SHUTDOWN_RETRY_MS = 15000UL;
const uint32_t SHUTDOWN_GRACE_MS = 60UL * 1000UL;
// PC817 outputs are active-low. The installed GPIO17 interface measures about
// 0.017 V while the Pi is running and about 0.58 V after the shutdown service
// releases the optocoupler. Keep a wide dead band between the calibrated ON
// and OFF thresholds so ambiguous readings fail closed.
const float ADS_PI_ON_MAX_V = 0.10f;
const float ADS_PI_OFF_MIN_V = 0.45f;
const float PC817_LOGICAL_HIGH_V = 3.30f;
const uint32_t ADS_PI_RAIL_ON_CONFIRM_MS = 10UL * 1000UL;
const uint32_t ADS_PI_RAIL_OFF_CONFIRM_MS = 30UL * 1000UL;
const float NO_ADS_RESTART_ARM_SOC = 3.0f;
const float AUTO_RESTORE_MIN_VOLTAGE = 13.60f;
const float AUTO_RESTORE_MIN_SOC = 7.0f;
const uint32_t AUTO_RESTORE_CONFIRM_MS = 2UL * 60UL * 1000UL;
const uint32_t UTILITY_RECOVERY_CANCEL_CONFIRM_MS = 30UL * 1000UL;
// A local W5500 link failure does not prove that Pi1/PixVirt is hung. Keep the
// destructive relay action disabled; link transitions are still monitored.
const bool ETH_LINK_WATCHDOG_ENABLED = false;
const uint8_t ETH_LINK_WATCHDOG_RELAY_INDEX = 0; // 0 = Pi1 relay, 1 = Pi2 relay
const uint32_t ETH_LINK_DOWN_POWER_CYCLE_MS = 90000UL;
const uint32_t ETH_LINK_POWER_CYCLE_COOLDOWN_MS = 300000UL;
const uint32_t I2C_BOOT_SETTLE_MS = 1500UL;
const uint32_t I2C_REDISCOVERY_INTERVAL_MS = 30000UL;
const uint32_t I2C_CLOCK_HZ = 50000UL;
const uint32_t NUT_ON_BATTERY_CONFIRM_MS = 5000UL;
const uint32_t NUT_UTILITY_RECOVERY_CONFIRM_MS = 30000UL;
// PVE-UPS is configured to request orderly host shutdown at 10% SOC. The Pico
// cannot authenticate that external request directly, so it only arms an
// expectation during a confirmed outage. Relay cutoff still requires the
// existing per-host ADS/PC817 running-to-final-OFF proof and the normal grace.
const float PVE_UPS_HANDOFF_SOC = 10.0f;
const uint32_t PVE_UPS_HANDOFF_RECOVERY_HOLD_MS = 5UL * 60UL * 1000UL;

const char* CALIBRATION_TOKEN = UPS_CALIBRATION_TOKEN;

const uint32_t PERSIST_MAGIC   = 0x55505332;  // "UPS2"
const uint16_t PERSIST_VERSION = 1;
const uint16_t PERSIST_FLAG_LOW_BATTERY_LOCKOUT = 1U << 0;
const uint16_t EEPROM_PAGE_SIZE = 64;

struct PiConfig {
  bool relayState;
  bool enabled;
  char shutdownUrl[96];
};

struct PersistedState {
  uint32_t magic;
  uint16_t version;
  uint16_t reserved0;
  float remainingWh;
  float remainingMah;
  float usableWh;
  float batteryCapacityAh;
  float usableCapacityPct;
  float shutdownSoc;
  float adsThresholdVolts;
  uint32_t shutdownDelaySec;
  uint32_t powerCycleMs;
  uint8_t relayActiveHigh;
  uint8_t relayPins[2];
  uint8_t relayState[2];
  uint8_t piEnabled[2];
  char shutdownUrl[2][96];
  uint32_t crc32;
};

struct SensorState {
  bool ltcPresent = false;
  bool adsPresent = false;
  bool ioPresent = false;
  bool eepromPresent = false;
  float vbus = 0.0f;
  float currentA = 0.0f;
  float powerW = 0.0f;
  float temperatureC = NAN;
  float soc = 50.0f;
  float remainingWh = (BATTERY_CAPACITY_AH * BATTERY_NOMINAL_V * USABLE_CAPACITY_PCT) * 0.5f;
  float remainingMah = (BATTERY_CAPACITY_AH * 1000.0f * USABLE_CAPACITY_PCT) * 0.5f;
  float runtimeMin = -1.0f;
  bool valid = false;
};

struct PiStatus {
  bool relayOn = true;
  bool sensedOn = false;
  bool sensedEstimated = true;
  float adsVolts = 0.0f;
};

enum BatteryFlowState : uint8_t {
  BATTERY_IDLE,
  BATTERY_CHARGING,
  BATTERY_DISCHARGING
};

enum NutPowerSource : uint8_t {
  NUT_POWER_UNKNOWN,
  NUT_POWER_MAINS,
  NUT_POWER_BATTERY
};

enum LowBatteryStage : uint8_t {
  LOW_BATTERY_IDLE,
  LOW_BATTERY_WAITING,
  LOW_BATTERY_DONE
};

enum PowerAction : uint8_t {
  POWER_ACTION_NONE,
  POWER_ACTION_RESTORE_ON
};

enum GracefulShutdownStage : uint8_t {
  GRACEFUL_SHUTDOWN_IDLE,
  GRACEFUL_SHUTDOWN_REQUESTING,
  GRACEFUL_SHUTDOWN_WAITING
};

struct GracefulShutdownState {
  GracefulShutdownStage stage = GRACEFUL_SHUTDOWN_IDLE;
  unsigned long lastAttemptMs = 0;
  unsigned long acceptedMs = 0;
};

struct PendingPowerAction {
  PowerAction action = POWER_ACTION_NONE;
  unsigned long dueMs = 0;
};

SensorState sensor;
PiConfig piConfig[2];
PiStatus piStatus[2];
PendingPowerAction powerActions[2];
GracefulShutdownState gracefulShutdowns[2];
unsigned long powerCycleStartedMs[2] = {0, 0};

EthernetServer httpServer(HTTP_PORT);
EthernetServer nutServer(NUT_PORT);
EthernetUDP mdnsUdp;
MDNS mdns(mdnsUdp);
EthernetClient mqttNetworkClient;
PubSubClient mqttClient(mqttNetworkClient);

unsigned long lastTelemetryMs = 0;
unsigned long lastMqttReconnectAttemptMs = 0;
unsigned long lastI2cRediscoveryMs = 0;
unsigned long ethLinkDownStartedMs = 0;
unsigned long lastEthLinkPowerCycleMs = 0;
bool lastEthLinkUp = false;
unsigned long lastSaveMs = 0;
unsigned long lastAnySaveMs = 0;
float lastSavedWh = 0.0f;
BatteryFlowState lastSavedState = BATTERY_IDLE;
unsigned long fullCandidateStartMs = 0;
unsigned long criticalCandidateStartMs = 0;
bool forceSave = false;

LowBatteryStage lowBatteryStage = LOW_BATTERY_IDLE;
unsigned long lowBatteryStageStartedMs = 0;
unsigned long autoRestoreCandidateStartMs = 0;
unsigned long shutdownRecoveryCandidateStartMs = 0;
bool lowBatteryLockout = false;
bool shutdownApiAttempted[2] = { false, false };
unsigned long shutdownAcceptedMs[2] = { 0, 0 };
unsigned long lastShutdownRetryMs = 0;
bool adsMissingLogged = false;
bool ltcReadFailureLogged = false;
bool adsReadFailureLogged[2] = { false, false };
bool lastPiSensedState[2] = { false, false };
bool lastPiSensedStateKnown[2] = { false, false };
bool adsPiRailSeenOn[2] = { false, false };
bool adsPiRailOffConfirmed[2] = { false, false };
unsigned long adsPiRailOnCandidateStartMs[2] = { 0, 0 };
unsigned long adsPiRailOffCandidateStartMs[2] = { 0, 0 };
unsigned long lastRelayCutoffBlockedLogMs[2] = { 0, 0 };
unsigned long lastLowBatteryCutoffBlockedLogMs = 0;
bool pveUpsHandoffArmed = false;
unsigned long pveUpsHandoffArmedMs = 0;
unsigned long pveUpsHandoffRecoveryStartMs = 0;
bool noAdsRestartPending = false;
bool noAdsRecoveryCycleStarted = false;
bool noAdsRecoveryCycleRequested[2] = { false, false };
unsigned long noAdsRecoveryCandidateStartMs = 0;
bool otaPendingBoot = false;
bool littleFsAvailable = false;
unsigned long otaBootStartedMs = 0;
bool restartRequested = false;
unsigned long restartDueMs = 0;
NutPowerSource nutPowerSource = NUT_POWER_UNKNOWN;
unsigned long nutOnBatteryCandidateStartMs = 0;
unsigned long nutUtilityRecoveryCandidateStartMs = 0;

// ============================================================================
// Utility
// ============================================================================
static float usableEnergyWh() {
  return BATTERY_CAPACITY_AH * BATTERY_NOMINAL_V * USABLE_CAPACITY_PCT;
}

static uint32_t crc32Update(uint32_t crc, uint8_t data) {
  crc ^= data;
  for (uint8_t i = 0; i < 8; i++) {
    crc = (crc & 1U) ? (crc >> 1U) ^ 0xEDB88320UL : (crc >> 1U);
  }
  return crc;
}

static uint32_t crc32Bytes(const uint8_t *data, size_t len) {
  uint32_t crc = 0xFFFFFFFFUL;
  for (size_t i = 0; i < len; i++) crc = crc32Update(crc, data[i]);
  return ~crc;
}

static uint32_t readLittleEndian32(const uint8_t *data) {
  return (uint32_t)data[0] |
         ((uint32_t)data[1] << 8U) |
         ((uint32_t)data[2] << 16U) |
         ((uint32_t)data[3] << 24U);
}

// RP2040 ROM validates the first-stage bootloader with CRC-32/MPEG-2 over
// bytes 0..251; bytes 252..255 contain the little-endian expected CRC.
static uint32_t rp2040Boot2Crc(const uint8_t *data) {
  uint32_t crc = 0xFFFFFFFFUL;
  for (size_t i = 0; i < 252; i++) {
    crc ^= (uint32_t)data[i] << 24U;
    for (uint8_t bit = 0; bit < 8; bit++) {
      crc = (crc & 0x80000000UL) ? (crc << 1U) ^ 0x04C11DB7UL : crc << 1U;
    }
  }
  return crc;
}

static bool otaValidateRp2040ImageHeader(const uint8_t *header, size_t imageSize) {
  if (imageSize < OTA_RP2040_HEADER_SIZE || (imageSize & 3U) != 0) return false;

  uint32_t expectedBoot2Crc = readLittleEndian32(header + 252);
  if (rp2040Boot2Crc(header) != expectedBoot2Crc) return false;

  // The vector table follows boot2 at offset 256 in an Arduino-Pico .bin.
  uint32_t initialStack = readLittleEndian32(header + 256);
  uint32_t resetVector = readLittleEndian32(header + 260);
  uint32_t resetAddress = resetVector & ~1UL;
  bool stackValid = initialStack >= 0x20000000UL && initialStack <= 0x20042000UL &&
                    (initialStack & 7U) == 0;
  bool resetValid = (resetVector & 1U) != 0 &&
                    resetAddress >= XIP_BASE + 256UL &&
                    resetAddress < XIP_BASE + imageSize;
  return stackValid && resetValid;
}

static void recoverI2cBusPins() {
  pinMode(I2C_SDA, INPUT_PULLUP);
  pinMode(I2C_SCL, INPUT_PULLUP);
  delay(20);

  Serial.printf("[I2C] Idle levels before recovery: SDA=%u SCL=%u\n",
                digitalRead(I2C_SDA) ? 1 : 0,
                digitalRead(I2C_SCL) ? 1 : 0);

  if (digitalRead(I2C_SDA) == LOW) {
    Serial.println("[I2C] SDA held low; pulsing SCL.");
    pinMode(I2C_SCL, OUTPUT);
    for (uint8_t i = 0; i < 9; i++) {
      digitalWrite(I2C_SCL, HIGH);
      delayMicroseconds(8);
      digitalWrite(I2C_SCL, LOW);
      delayMicroseconds(8);
    }
    digitalWrite(I2C_SCL, HIGH);
    delayMicroseconds(8);
  }

  pinMode(I2C_SDA, INPUT_PULLUP);
  pinMode(I2C_SCL, INPUT_PULLUP);
  delay(20);
  Serial.printf("[I2C] Idle levels after recovery: SDA=%u SCL=%u\n",
                digitalRead(I2C_SDA) ? 1 : 0,
                digitalRead(I2C_SCL) ? 1 : 0);
}

static bool i2cDevicePresent(uint8_t addr) {
  Wire.beginTransmission(addr);
  return Wire.endTransmission() == 0;
}

static void i2cScan() {
  Serial.printf("[I2C] Idle levels before scan: SDA=%u SCL=%u\n",
                digitalRead(I2C_SDA) ? 1 : 0,
                digitalRead(I2C_SCL) ? 1 : 0);
  Serial.println("I2C scan:");
  uint8_t count = 0;
  for (uint8_t addr = 0x08; addr <= 0x77; addr++) {
    if (i2cDevicePresent(addr)) {
      Serial.printf("  0x%02X\n", addr);
      count++;
    }
  }
  if (count == 0) Serial.println("  (no devices detected)");
}

static void logModulePresence(const char *name, uint8_t addr, bool present) {
  Serial.printf("[DISCOVERY] %s at 0x%02X: %s\n", name, addr, present ? "found" : "missing");
}

static bool findDeviceInRange(const char *name, uint8_t startAddr, uint8_t endAddr, uint8_t &foundAddr) {
  Serial.printf("[DISCOVERY] Searching %s from 0x%02X to 0x%02X\n", name, startAddr, endAddr);
  for (uint8_t addr = startAddr; addr <= endAddr; addr++) {
    if (i2cDevicePresent(addr)) {
      foundAddr = addr;
      Serial.printf("[DISCOVERY] %s matched at 0x%02X\n", name, addr);
      return true;
    }
  }
  Serial.printf("[DISCOVERY] %s not found in range 0x%02X-0x%02X\n", name, startAddr, endAddr);
  return false;
}

static BatteryFlowState batteryFlowState(float currentA) {
  if (currentA < -CURRENT_DEADBAND_A) return BATTERY_DISCHARGING;
  if (currentA >  CURRENT_DEADBAND_A) return BATTERY_CHARGING;
  return BATTERY_IDLE;
}

static void updateNutPowerSource() {
  unsigned long now = millis();

  // A committed low-battery shutdown is still an outage until the existing
  // relay-restore state machine has confirmed utility recovery and re-enabled
  // the outputs. This also preserves the outage across a Pico reboot.
  if (lowBatteryStage != LOW_BATTERY_IDLE || lowBatteryLockout) {
    nutPowerSource = NUT_POWER_BATTERY;
    nutOnBatteryCandidateStartMs = 0;
    nutUtilityRecoveryCandidateStartMs = 0;
    return;
  }

  if (!sensor.valid) {
    nutOnBatteryCandidateStartMs = 0;
    nutUtilityRecoveryCandidateStartMs = 0;
    return;
  }

  const bool discharging = sensor.currentA < -CURRENT_DEADBAND_A;
  const bool charging = sensor.currentA > CURRENT_DEADBAND_A;
  const bool utilityRecovery = sensor.vbus >= AUTO_RESTORE_MIN_VOLTAGE &&
                               sensor.currentA >= -CURRENT_DEADBAND_A;

  if (nutPowerSource == NUT_POWER_BATTERY) {
    nutOnBatteryCandidateStartMs = 0;
    if (!utilityRecovery) {
      nutUtilityRecoveryCandidateStartMs = 0;
      return;
    }

    if (nutUtilityRecoveryCandidateStartMs == 0) {
      nutUtilityRecoveryCandidateStartMs = now;
      return;
    }
    if (now - nutUtilityRecoveryCandidateStartMs < NUT_UTILITY_RECOVERY_CONFIRM_MS) return;

    nutPowerSource = NUT_POWER_MAINS;
    nutUtilityRecoveryCandidateStartMs = 0;
    Serial.println("[NUT] Utility recovery confirmed; status -> OL.");
    return;
  }

  nutUtilityRecoveryCandidateStartMs = 0;
  if (discharging) {
    if (nutOnBatteryCandidateStartMs == 0) {
      nutOnBatteryCandidateStartMs = now;
      return;
    }
    if (now - nutOnBatteryCandidateStartMs < NUT_ON_BATTERY_CONFIRM_MS) return;

    nutPowerSource = NUT_POWER_BATTERY;
    nutOnBatteryCandidateStartMs = 0;
    Serial.println("[NUT] Battery discharge confirmed; status -> OB.");
    return;
  }

  nutOnBatteryCandidateStartMs = 0;
  // Positive charge current is direct evidence that the charger is present.
  // Near-zero current is accepted as mains only at charger-level voltage.
  if (charging || utilityRecovery) {
    const bool changed = nutPowerSource != NUT_POWER_MAINS;
    nutPowerSource = NUT_POWER_MAINS;
    if (changed) Serial.println("[NUT] Charger/utility detected; status -> OL.");
  }
}

static float runtimeMinutes(float remainingWh, float loadW) {
  loadW = fabsf(loadW);
  if (loadW < MIN_RUNTIME_LOAD_W) return -1.0f;
  return remainingWh / loadW * 60.0f;
}

static bool otaWritePendingAttempts(uint8_t attempts) {
  File f = LittleFS.open(OTA_PENDING_FILE, "w");
  if (!f) return false;
  bool ok = f.write(&attempts, 1) == 1;
  f.close();
  return ok;
}

static bool otaScheduleFile(const char *path) {
  if (!LittleFS.exists(path)) return false;
  picoOTA.begin();
  if (!picoOTA.addFile(path)) return false;
  return picoOTA.commit();
}
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
void loop() {
  rp2040.wdt_reset();
  otaMarkHealthyIfReady();
  if (restartRequested && millis() >= restartDueMs) {
    mqttClient.disconnect();
    delay(20);
    rp2040.reboot();
  }
  Ethernet.maintain();
  mdns.run();
  mqttConnectIfNeeded();
  mqttClient.loop();
  processEthernetLinkWatchdog();
  handleNUT();
  handleHTTP();
  processManualGracefulShutdowns();

  if (millis() - lastI2cRediscoveryMs >= I2C_REDISCOVERY_INTERVAL_MS) {
    lastI2cRediscoveryMs = millis();
    if (!sensor.ltcPresent || !sensor.adsPresent || !sensor.ioPresent || !sensor.eepromPresent) {
      Serial.println("[I2C] Re-scanning missing devices.");
      discoverI2cDevices(true, true);
    }
  }

  for (uint8_t i = 0; i < 2; i++) {
    if (powerActions[i].action == POWER_ACTION_RESTORE_ON && millis() >= powerActions[i].dueMs) {
      Serial.printf("[POWER] Pi%u power-cycle restore on\n", i + 1);
      if (applyRelayState(i, true)) {
        powerActions[i].action = POWER_ACTION_NONE;
        powerCycleStartedMs[i] = 0;
      } else {
        powerActions[i].dueMs = millis() + 1000UL;
      }
    } else if (powerActions[i].action == POWER_ACTION_RESTORE_ON &&
               powerCycleStartedMs[i] != 0 &&
               millis() - powerCycleStartedMs[i] >= POWER_CYCLE_FAILSAFE_MS) {
      Serial.printf("[POWER] Pi%u power-cycle failsafe restore on\n", i + 1);
      if (applyRelayState(i, true)) {
        powerActions[i].action = POWER_ACTION_NONE;
        powerCycleStartedMs[i] = 0;
      } else {
        powerActions[i].dueMs = millis() + 1000UL;
      }
    }
  }

  if (millis() - lastTelemetryMs >= TELEMETRY_INTERVAL_MS) {
    lastTelemetryMs = millis();
    updateBatteryModel();
    refreshPiStatusFromAds();
    savePersistedStateIfNeeded();
    processLowBatteryProtection();
    updateNutPowerSource();
    mqttPublishState();

    Serial.printf(
      "SOC=%.1f%% Wh=%.2f Runtime=%.1f V=%.2f I=%.3f T=%.1fC Pi1=%d/%.2fV Pi2=%d/%.2fV\n",
      sensor.soc,
      sensor.remainingWh,
      sensor.runtimeMin,
      sensor.vbus,
      sensor.currentA,
      finiteOrZero(sensor.temperatureC),
      piStatus[0].sensedOn ? 1 : 0,
      displayedPiVoltage(0),
      piStatus[1].sensedOn ? 1 : 0,
      displayedPiVoltage(1)
    );
  }
}

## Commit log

2026-09-20 Initial public release of Pico W5500 UPS controller
2026-09-20 Document hardware BOM, DeskPi build, and PCB files
    [w5500.kicad_pcb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]
